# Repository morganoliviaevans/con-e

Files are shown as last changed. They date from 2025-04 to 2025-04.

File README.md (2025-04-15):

# CON-E: Conical Ocular and Navigation - Explorer

CON-E is a computer vision-enabled robotic traffic cone designed to be more than just a passive roadside object. Built during BitHacks 2025, CON-E explores how expressive robotics and assistive autonomy can bring personality and utility to simple infrastructure. CON-E uses a 2-wheel drive system to move, tracks orange-colored objects using a camera and computer vision, plays audio through a speaker, and changes an RGB LED to reflect its mood or internal state.

CON-E was awarded “Best Meme Hack” at BitHacks 2025.

___

### Components

CON-E is built inside a real traffic cone with tightly integrated electronics and 3D printed mounting. The system includes:

#### Electronics & Control

- RGB LED – system state indication
- 6V DC Gearbox Motors (x2) – cone movement
- Webcam – camera input for vision tracking
- L298N Motor Driver – drives motors from ESP32
- Raspberry Pi 4 – computer vision and state logic
- ESP32-S3 Dev Board – motors, RGB LED, and audio control
- DFPlayer Mini and Speaker – audio playback module, voice and sound effects

#### Power

- 9V Battery – powers ESP32 subsystem
- USB Power Bank – powers Raspberry Pi

#### Mechanical and Design

- Traffic Cone – cone body for housing
- 3D Prints - custom designs for base plate and internal hardware housing

___

### Software & Technologies

- C++
- Python
- OpenCV
- ESP-IDF
- VSCode
- Raspberry Pi OS
- Arduino and PlatformIO
- Onshape – CAD design for 3D parts
- Bambu Studio – slicing and printing

___

### What’s Next

This is just the beginning. CON-E is a prototype—an early proof of concept. Future directions include:

- AI and ML integration
- Voice control and speech recognition
- Omnidirectional wheels for improved mobility
- An LCD screen for dynamic facial expressions
- Swarm functionality for multi-cone deployments
- A mobile app for remote control and coordination

___

### Media

#### Meet the Team

<div style="text-align: center;">
  Li Keller<br/>
  Li Keller
</div>
<br>

<div style="text-align: center;">
  David<br/>
  Erik David Piolo
</div>
<br>

<div style="text-align: center;">
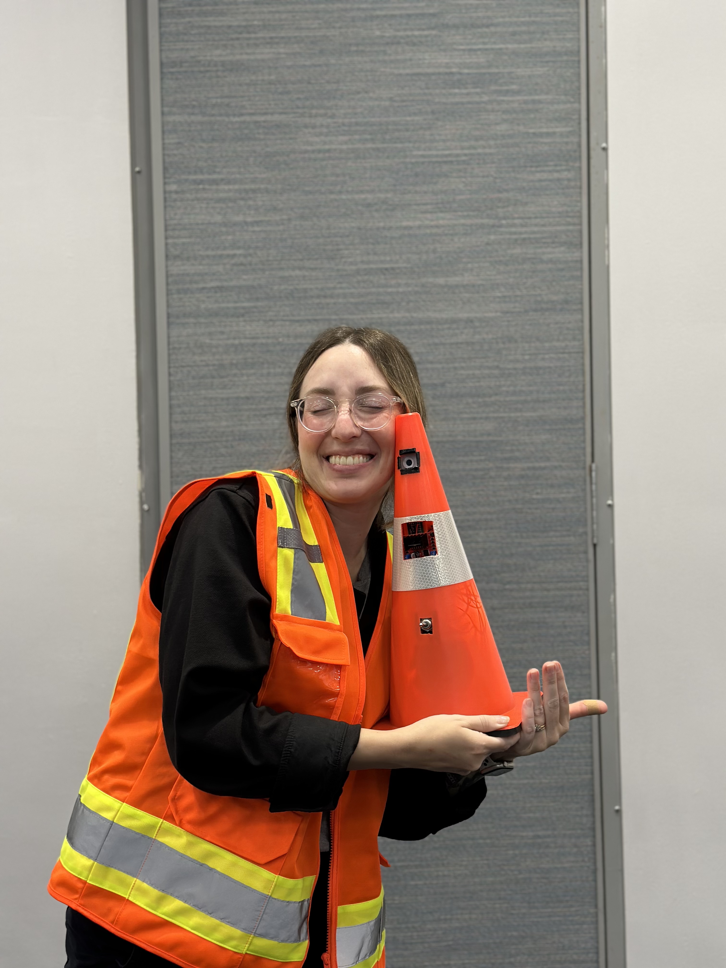
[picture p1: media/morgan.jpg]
Erik David Piolo
  <br/>
  Morgan Olivia Newton
</div>
<br>

<div style="text-align: center;">
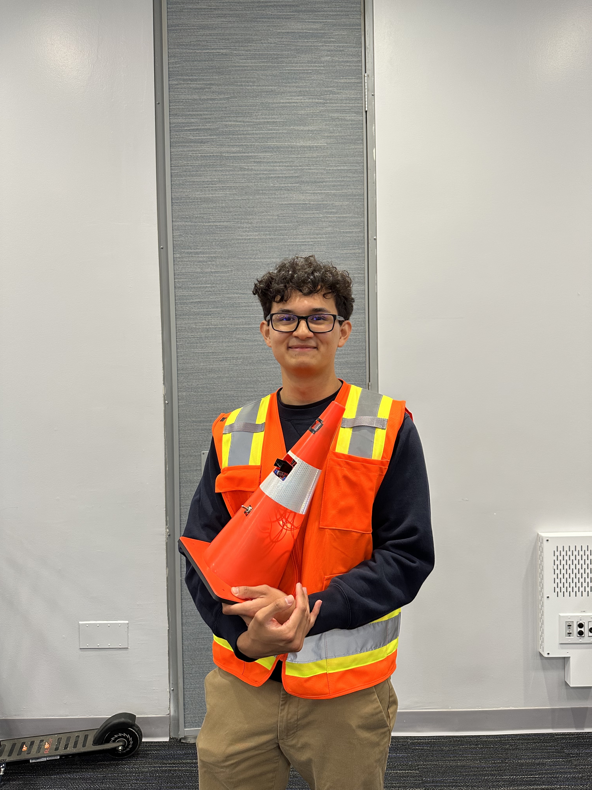
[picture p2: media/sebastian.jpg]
Sebastian Ala Torre
  <br/>
  Sebastian Ala Torre
</div>
<br>

<br>
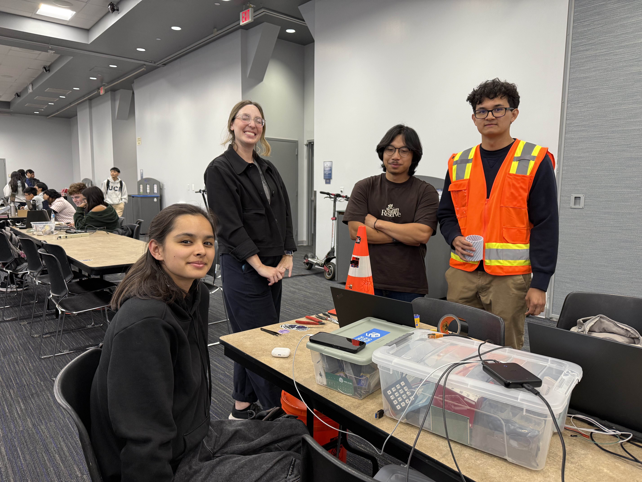
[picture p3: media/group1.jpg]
Group Photo 1

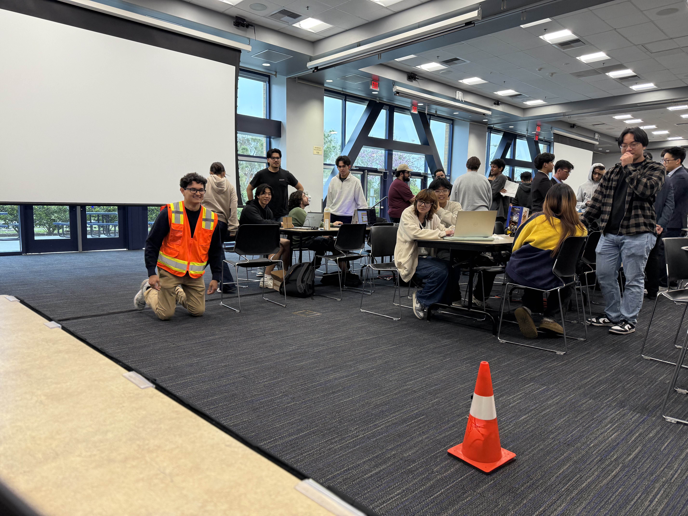
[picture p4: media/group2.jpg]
Group Photo 2

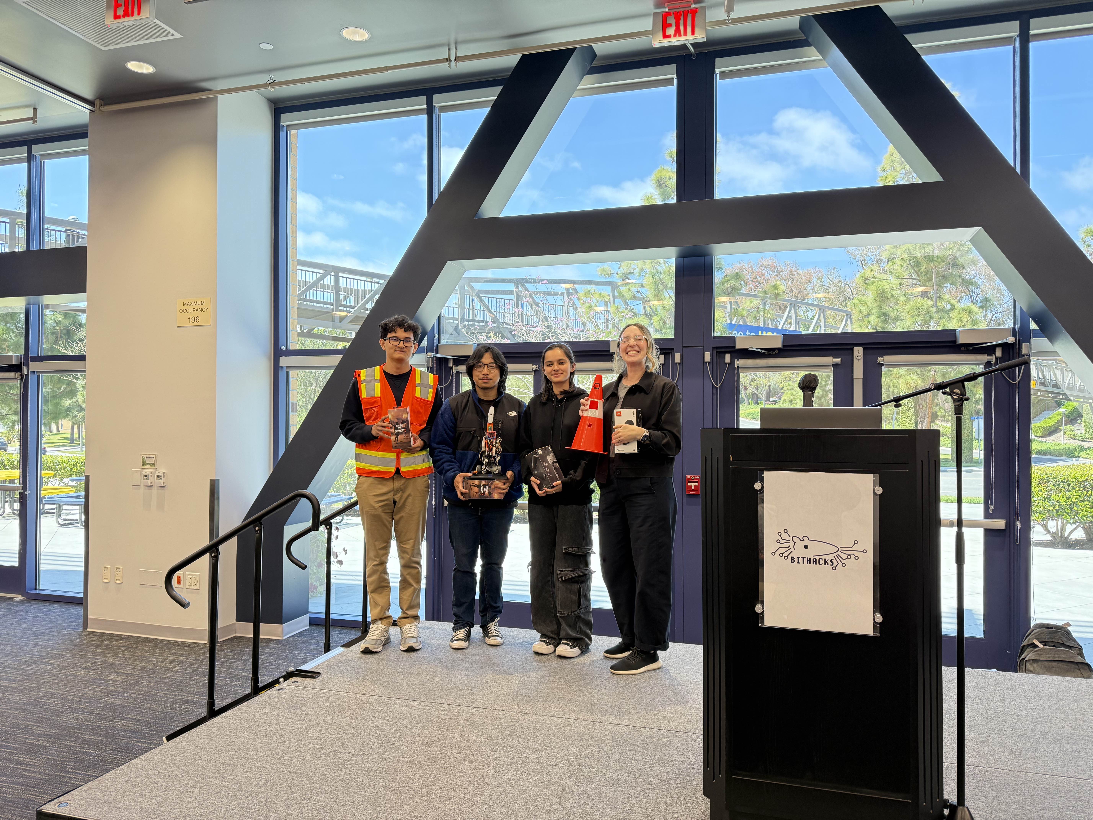
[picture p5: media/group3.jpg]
Group Photo 3

Group Photo 4

#### Internal Components

Internal View 1
Internal View 2

#### Demo

- [Startup Sound Test](/media/startup-test.mov)
- [Demo Clip 1](/media/demo1.mov)
- [Demo Clip 2](/media/demo2.mov)

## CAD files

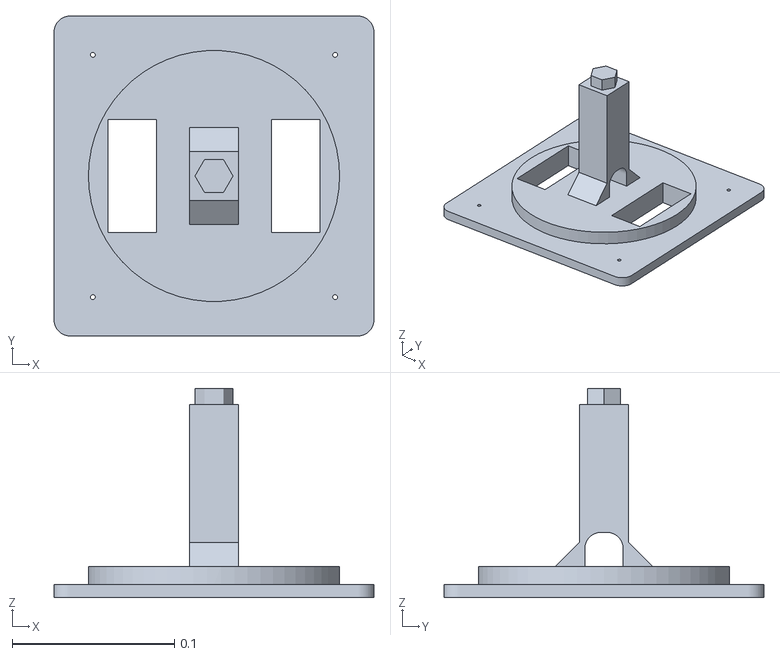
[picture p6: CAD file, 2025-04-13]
stl/main-base.stl
0.198 x 0.198 x 0.129

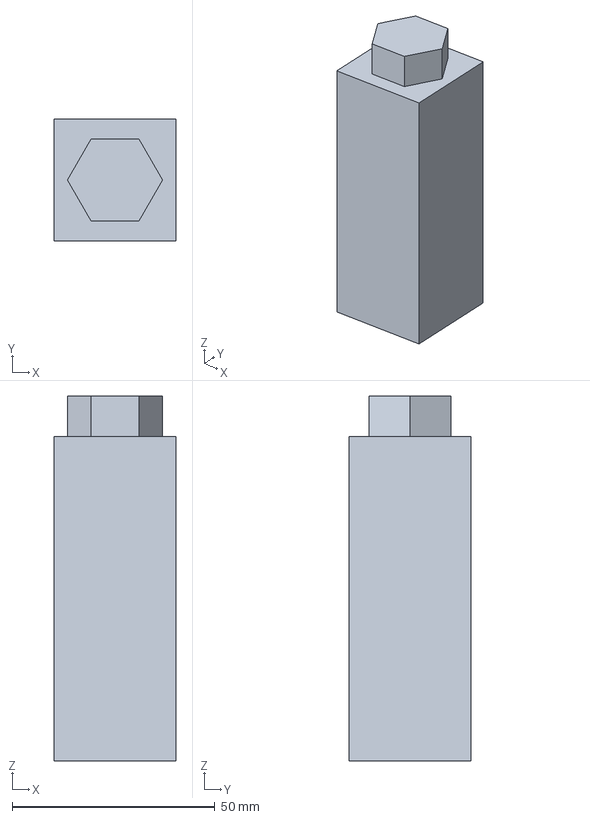
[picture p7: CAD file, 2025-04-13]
stl/extender-base.3mf
30.0 x 30.0 x 90.0 mm

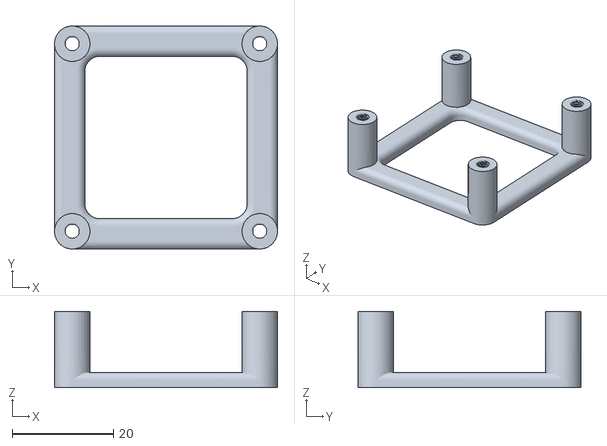
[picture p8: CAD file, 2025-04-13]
stl/L298N-plate.stl
44.0 x 44.0 x 15.0

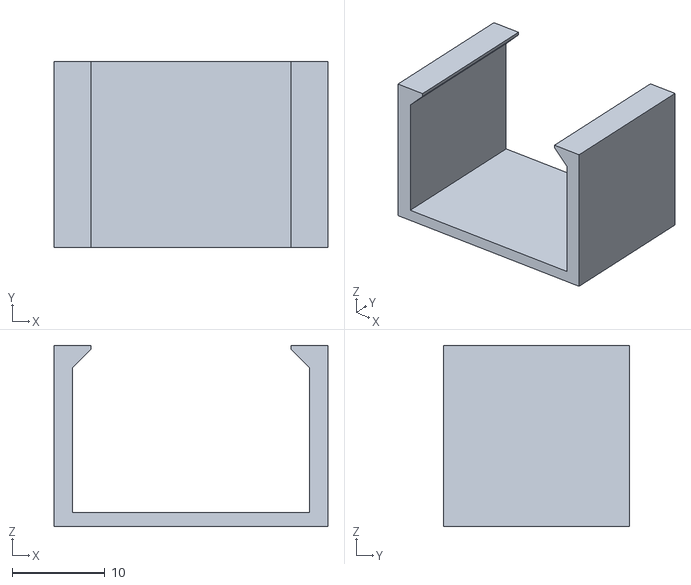
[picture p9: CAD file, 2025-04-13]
stl/9v-clip.stl
29.5 x 20.0 x 19.5

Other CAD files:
stl/final-lower-extender.gcode.3mf
stl/extender-base.stl

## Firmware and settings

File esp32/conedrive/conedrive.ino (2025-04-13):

#include "esp-speaker.h"
#include "esp-led.h"

// Objects and Rand Vars
Led led; // RGB Led obj
Speaker speaker;

unsigned long lastSoundTime = 0;
unsigned long nextSoundInterval = 0;

const int STARTUP = 1;
// Define motor control pins
const int IN1 = 4;
const int IN2 = 5;
const int ENA = 14;

const int IN3 = 19;
const int IN4 = 20;
const int ENB = 21;


bool isCenter = false;
bool isLeft = false;
bool isRight = false;


void rotateLeft();
//rotate 1 second

void setup() {
  // Set pins as output
  Serial.begin(9600);


  led.setup();

  // seeding randomizer
  randomSeed(analogRead(A0));
  lastSoundTime = millis();
  nextSoundInterval = random(4000, 15000); // 8 - 15 sec

  pinMode(IN1, OUTPUT);
  pinMode(IN2, OUTPUT);
  pinMode(ENA, OUTPUT);

  pinMode(STARTUP, INPUT_PULLDOWN);

  pinMode(IN3, OUTPUT);
  pinMode(IN4, OUTPUT);
  pinMode(ENB, OUTPUT);
  
  // Start with motor stopped
  digitalWrite(IN1, LOW);
  digitalWrite(IN2, LOW);
  analogWrite(ENA, 0); // 0-255 (PWM)

  digitalWrite(IN2, LOW);
  digitalWrite(IN3, LOW);
  analogWrite(ENB, 0); // 0-255 (PWM)

  while (digitalRead(STARTUP) != HIGH)
  {
   delay(1000);
  }

  speaker.setup();

}

void forward();
void stopMotor();
void backward();
void spin();
void rotateLeft();
void rotateRight();

void resetup() {
  while(digitalRead(STARTUP) == LOW)
    delay(1000);
  speaker.player.playFolder(1, Speaker::STARTUP);
  lastSoundTime = millis();
}

void loop() {
  if(digitalRead(STARTUP) == LOW)
    resetup();
  led.flash();
  if (Serial.available() > 0) {
    char command = Serial.read();
//hi meow :3
    switch (command) {
      case 'f': forward();
                led.setMode(Led::FLASH_GREEN);
                                            break;
      case 's': stopMotor();
                led.setMode(Led::FLASH_RED);
                speaker.playTrack(Speaker::WHEET_WHEW);
                                            break;
      case 'b': backward(); 
                led.setMode(Led::FLASH_RED);
                speaker.playTrack(Speaker::BACKUP);
                                            break;
      case 'r': rotateRight();              break;
      case 'l': rotateLeft();               break;
      case 'p': spin(); 
                led.setMode(Led::POLICE); 
                speaker.playTrack(Speaker::SIREN);
                                            break;
      case 'i': led.setMode(Led::IDLE);     break; // idle
      case 'a': led.setMode(Led::CYCLE);    break; // active
      case 'z': led.setMode(Led::SLEEP);    break; // sleep
    }
  }
  unsigned long now = millis();
  if(now - lastSoundTime >= nextSoundInterval) {
    int randomTrack = random(0, speaker.Sounds);
    speaker.playTrack((Speaker::Voiceline)randomTrack);

    lastSoundTime = now;
    nextSoundInterval = random(4000, 15000);
  }
}

void rotateLeft()
{

digitalWrite(IN1,LOW);
digitalWrite(IN2,HIGH);
analogWrite(ENA, 180); // 0-255 (PWM)
digitalWrite(IN3,LOW);
digitalWrite(IN4,HIGH);
analogWrite(ENB, 180); // 0-255 (PWM)
}

void forward()
{

digitalWrite(IN1,HIGH);
digitalWrite(IN2,LOW);
analogWrite(ENA, 255); // 0-255 (PWM)
digitalWrite(IN3,LOW);
digitalWrite(IN4,HIGH);
analogWrite(ENB, 255); // 0-255 (PWM)

/// led flashing
}

void backward()
{
digitalWrite(IN1,LOW);
digitalWrite(IN2,HIGH);
analogWrite(ENA, 255); // 0-255 (PWM)
digitalWrite(IN3,HIGH);
digitalWrite(IN4,LOW);
analogWrite(ENB, 255); // 0-255 (PWM)
}

void rotateRight()
{
digitalWrite(IN1,HIGH);
digitalWrite(IN2,LOW);
analogWrite(ENA, 180); // 0-255 (PWM)
digitalWrite(IN3,HIGH);
digitalWrite(IN4,LOW);
analogWrite(ENB, 180); // 0-255 (PWM)
}

void stopMotor() {
  digitalWrite(IN1, LOW);
  digitalWrite(IN2, LOW);
  analogWrite(ENA, 0);

  digitalWrite(IN3, LOW);
  digitalWrite(IN4, LOW);
  analogWrite(ENB, 0);
}

void spin() {

 rotateRight();
 delay(5000);
 stopMotor();
}

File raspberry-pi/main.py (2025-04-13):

from PIL import Image
from enum import Enum
import numpy as np
import random
import cv2
import serial
import time


class DeviceState(Enum):
    PLAY_CAMERA = 0
    PLAY_REMOTE = 1
    IDLE = 2
    SLEEP = 3


class Direction(Enum):
    STOP = 0
    ROTATE_LEFT = 1
    ROTATE_RIGHT = 2
    SPIN = 3
    FORWARD = 4
    BACKWARD = 5


currentState = DeviceState.IDLE

# TODO: fine tune the area threshold
AREA_LOWER_THRESHOLD = 40000
AREA_UPPER_THRESHOLD = 130000


def get_limits(color):
    c = np.uint8([[color]])
    hsvC = cv2.cvtColor(c, cv2.COLOR_BGR2HSV)

    # calculate tolerances for the orange
    lowerLimit = hsvC[0][0][0] - 10, 120, 200
    upperLimit = hsvC[0][0][0] + 10, 255, 255

    lowerLimit = np.array(lowerLimit, dtype=np.uint8)
    upperLimit = np.array(upperLimit, dtype=np.uint8)

    return lowerLimit, upperLimit


def get_direction(y1, y2):
    midpoint = (y1 + (y1 + y2)) / 2

    if midpoint < 200:
        return Direction.ROTATE_LEFT
    elif midpoint >= 400:
        return Direction.ROTATE_RIGHT
    else:
        return Direction.STOP


def area(x1, x2, y1, y2):
    return (x2 - x1) * (y2 - y1)


def loop(cam, arduino):
    global currentState
    orange = [12, 95, 247]

    # Last State
    lastSeen = time.time()
    lastSeenOrange = None

    # Last time since random sound effect
    lastSoundEffect = time.time() + random.randint(30, 60)

    while True:
        direction = Direction.STOP
        # OpenCV stuff
        ret, frame = cam.read()
        cv2.normalize(frame, frame, 0, 255, cv2.NORM_MINMAX)

        hsvImage = cv2.cvtColor(frame, cv2.COLOR_BGR2HSV)
        lowerLimit, upperLimit = get_limits(orange)

        mask = cv2.inRange(hsvImage, lowerLimit, upperLimit)
        mask_ = Image.fromarray(mask)
        bbox = mask_.getbbox()

        if bbox is not None:
            lastSeen = time.time()
            x1, y1, x2, y2 = bbox

            bbox_area = area(x1, x2, y1, y2)
            print(bbox_area)

            orientation = get_direction(y1, y2)

            if bbox_area < AREA_LOWER_THRESHOLD and orientation is Direction.STOP:
                direction = Direction.FORWARD
            elif bbox_area > AREA_UPPER_THRESHOLD and orientation is Direction.STOP:
                direction = Direction.BACKWARD
            else:
                direction = orientation

            frame = cv2.rectangle(frame, (x1, y1), (x2, y2), (0, 255, 0), 5)

            # Go back to play state if orange for >= 5s
            if lastSeenOrange is None:
                lastSeenOrange = time.time()
            elif time.time() - lastSeenOrange >= 5:
                if currentState != DeviceState.PLAY_CAMERA:
                    arduino.write(b"a")
                    print("going back to play_camera")
                    currentState = DeviceState.PLAY_CAMERA
        # if bbox is None
        else:
            lastSeenOrange = None
            elapsed = time.time() - lastSeen

            if elapsed > 30:
                if currentState != DeviceState.SLEEP:
                    arduino.write(b"z")
                    print("sleeping")
                    currentState = DeviceState.SLEEP
            elif elapsed > 15:
                if currentState != DeviceState.IDLE:
                    arduino.write(b"i")
                    print("idling")
                    currentState = DeviceState.IDLE

        # show cv frames
        cv2.imshow("frame", mask)
        cv2.imshow("original", frame)

        # Check the state of the device
        match currentState:
            case DeviceState.PLAY_CAMERA:
                # Send signal for random sound effect
                if time.time() >= lastSoundEffect:
                    arduino.write(b"m")
                    print("sent random sound effect")
                    lastSoundEffect = time.time() + random.randint(30, 60)

                # do something based off the direction
                match direction:
                    case Direction.FORWARD:
                        arduino.write(b"f")
                        print("forward")
                    case Direction.BACKWARD:
                        arduino.write(b"b")
                        print("backward")
                    case Direction.STOP:
                        arduino.write(b"s")
                        print("stop")
                    case Direction.ROTATE_LEFT:
                        arduino.write(b"l")
                        print("left")
                    case Direction.ROTATE_RIGHT:
                        arduino.write(b"r")
                        print("right")
            case DeviceState.IDLE:
                arduino.write(b"s")
                print("in idle state")
            case DeviceState.SLEEP:
                print("sleeping")

        if cv2.waitKey(1) & 0xFF == ord("q"):
            break

    cam.release()
    cv2.destroyAllWindows()


if __name__ == "__main__":
    cam = cv2.VideoCapture(0)
    arduino = serial.Serial("/dev/ttyUSB0", 9600)
    time.sleep(2)

    try:
        loop(cam, arduino)
    except KeyboardInterrupt:
        cam.release()
        cv2.destroyAllWindows()

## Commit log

2025-04-12 no 3 wheel drive :(
2025-04-13 merge RPi modules (#5)
    * feat: implement orange color detection
    * refactor: separate into functions
    * feat: begin serial communication between esp32 (#2)
    * feat: implement orange color detection
    * refactor: separate into functions
    * feat: implement serial connection between esp32
    * fix: rotate when object is left/right
    * fix: invert left/right
    the camera is flipped lol
    * fix: adjust camera brightness
    * revert back to mask
    * fix: adjust orange detection tolerances
    * feat: implement RPi movement (#4)
    * create area function for bbox
    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
    [main.py]
2025-04-13 Adding custom 3D modeling directory
    [9v-clip.stl, L298N-plate.stl, extender-base.3mf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]
2025-04-13 feat: implement esp32 functionality (#6)
    * Combined everythinggggggg
    * fixing pinouts for speaker
    * fixed start up, more frequent voice lines
    * burh
    * fix startup getting stuck in beginning
    ---------
    [conedrive.ino, esp-led.cpp, esp-led.h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]
